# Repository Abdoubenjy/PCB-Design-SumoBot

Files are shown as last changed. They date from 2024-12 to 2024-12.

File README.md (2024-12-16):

# Sumo hardware
This repository contains the schematic and PCB design of a mini-class Sumobot (500g 10x10cm),
created in KiCad. It's a 2-layer PCB with microcontroller MSP430G2553IPW28,
regulators 3.3V (AMS1117-3.3) and 5V (MP2359), two motor drivers TB6612FNG, IR receiver TSP382, and
circuit protection (RS3E075AT).

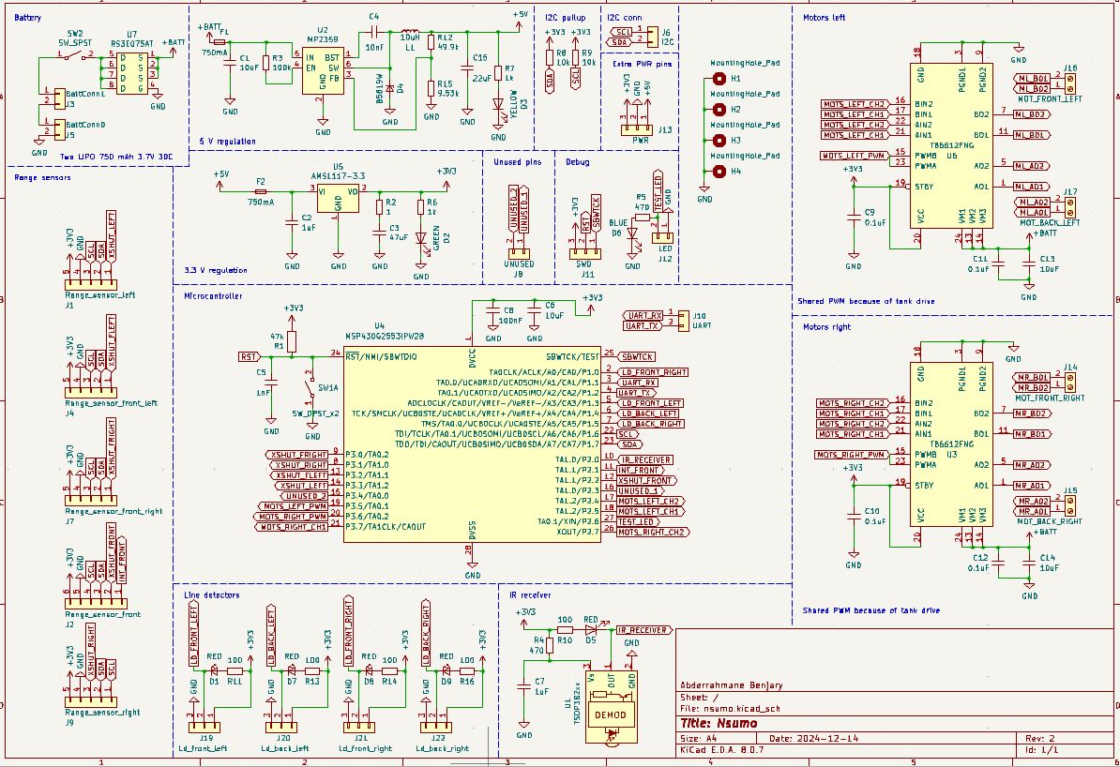
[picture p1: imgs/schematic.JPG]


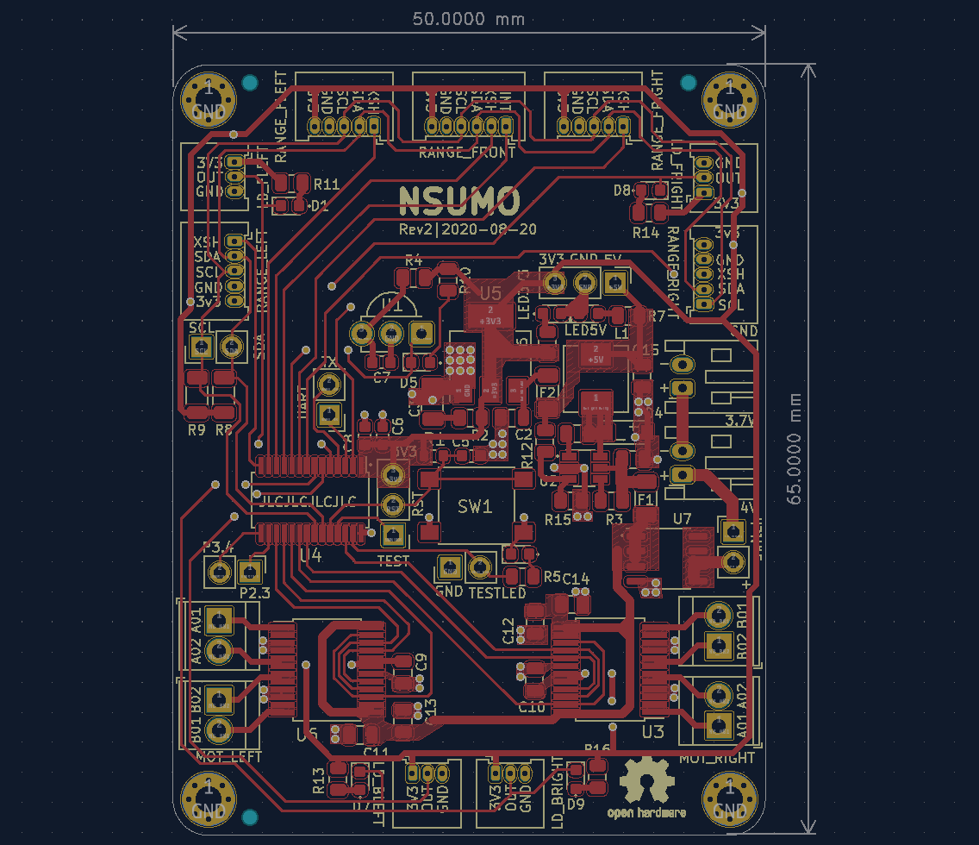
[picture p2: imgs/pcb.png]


## Setup
Import the project into KiCad >6.0 and make sure you have the "default global symbol library table"
and the "default footprint library" available. KiCad should find the 3Dmodels and symbols under _libs/_
automatically. You must manually import the footprints under _libs/footprints/_ (select "file/add library"
from the menu in the footprint editor and add them to the project).

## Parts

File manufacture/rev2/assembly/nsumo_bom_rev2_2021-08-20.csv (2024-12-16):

Comment | Designator | Footprint | LCSC Part #
10uF Unpolarized capacitor, small symbol | C13,C14,C1,C6 | C_0603_1608Metric | C19702
22uF Unpolarized capacitor, small symbol | C15 | C_0805_2012Metric | C45783
47uF Unpolarized capacitor, small symbol | C3 | C_1206_3216Metric | C96123
10nF Unpolarized capacitor, small symbol | C4 | C_0805_2012Metric | C1710
1nF Unpolarized capacitor, small symbol | C5 | C_0603_1608Metric | C1588
1uF Unpolarized capacitor, small symbol | C7,C2 | C_0805_2012Metric | C28323
100nF Unpolarized capacitor, small symbol | C8 | C_0603_1608Metric | C14663
0.1uF Unpolarized capacitor, small symbol | C9,C11,C12,C10 | C_0805_2012Metric | C49678
GREEN Light emitting diode | D2 | LED_0603_1608Metric | C72043
YELLOW Light emitting diode | D3 | LED_0603_1608Metric | C72038
B5819W Zener diode, small symbol | D4 | D_SOD-123 | C8598
RED Light emitting diode | D5 | LED_0603_1608Metric | C2286
BLUE Light emitting diode | D6 | LED_0603_1608Metric | C72041
RED Light emitting diode, small symbol | D7,D8,D9,D1 | LED_0603_1608Metric | C2286
750mA Fuse, small symbol | F2,F1 | Fuse_1206_3216Metric
MountingHole_Pad Mounting Hole with connection | H1,H2,H3,H4 | MountingHole_2.2mm_M2_Pad_Via
Range_sensor_left Generic connector, single row, 01x05, script generated (kicad-library-utils/schlib/autogen/connector/) | J1 | Molex_PicoBlade_53048-0510_1x05_P1.25mm_Horizontal
UART Generic connector, single row, 01x02, script generated (kicad-library-utils/schlib/autogen/connector/) | J10 | PinHeader_1x02_P2.54mm_Vertical
SWD Generic connector, single row, 01x03, script generated (kicad-library-utils/schlib/autogen/connector/) | J11 | PinHeader_1x03_P2.54mm_Vertical
LED Generic connector, single row, 01x02, script generated (kicad-library-utils/schlib/autogen/connector/) | J12 | PinHeader_1x02_P2.54mm_Vertical
PWR Generic connector, single row, 01x03, script generated (kicad-library-utils/schlib/autogen/connector/) | J13 | PinHeader_1x03_P2.54mm_Vertical
MOT_FRONT_RIGHT Generic screw terminal, single row, 01x02, script generated (kicad-library-utils/schlib/autogen/connector/) | J14 | TerminalBlock_TE_282834-2_1x02_P2.54mm_Horizont
MOT_BACK_RIGHT Generic screw terminal, single row, 01x02, script generated (kicad-library-utils/schlib/autogen/connector/) | J15 | TerminalBlock_TE_282834-2_1x02_P2.54mm_Horizont
MOT_FRONT_LEFT Generic screw terminal, single row, 01x02, script generated (kicad-library-utils/schlib/autogen/connector/) | J16 | TerminalBlock_TE_282834-2_1x02_P2.54mm_Horizont
MOT_BACK_LEFT Generic screw terminal, single row, 01x02, script generated (kicad-library-utils/schlib/autogen/connector/) | J17 | TerminalBlock_TE_282834-2_1x02_P2.54mm_Horizont
Ld_front_left Generic connector, single row, 01x03, script generated (kicad-library-utils/schlib/autogen/connector/) | J19 | Molex_PicoBlade_53048-0310_1x03_P1.25mm_Horizontal
Range_sensor_front Generic connector, single row, 01x06, script generated (kicad-library-utils/schlib/autogen/connector/) | J2 | Molex_PicoBlade_53048-0610_1x06_P1.25mm_Horizontal
Ld_back_left Generic connector, single row, 01x03, script generated (kicad-library-utils/schlib/autogen/connector/) | J20 | Molex_PicoBlade_53048-0310_1x03_P1.25mm_Horizontal
Ld_front_right Generic connector, single row, 01x03, script generated (kicad-library-utils/schlib/autogen/connector/) | J21 | Molex_PicoBlade_53048-0310_1x03_P1.25mm_Horizontal
Ld_back_right Generic connector, single row, 01x03, script generated (kicad-library-utils/schlib/autogen/connector/) | J22 | Molex_PicoBlade_53048-0310_1x03_P1.25mm_Horizontal
BattConn1 Generic connector, single row, 01x02, script generated (kicad-library-utils/schlib/autogen/connector/) | J3 | JST_PH_S2B-PH-K_1x02_P2.00mm_Horizontal
Range_sensor_front_left Generic connector, single row, 01x05, script generated (kicad-library-utils/schlib/autogen/connector/) | J4 | Molex_PicoBlade_53048-0510_1x05_P1.25mm_Horizontal
BattConn0 Generic connector, single row, 01x02, script generated (kicad-library-utils/schlib/autogen/connector/) | J5 | JST_PH_S2B-PH-K_1x02_P2.00mm_Horizontal
I2C Generic connector, single row, 01x02, script generated (kicad-library-utils/schlib/autogen/connector/) | J6 | PinHeader_1x02_P2.54mm_Vertical
Range_sensor_front_right Generic connector, single row, 01x05, script generated (kicad-library-utils/schlib/autogen/connector/) | J7 | Molex_PicoBlade_53048-0510_1x05_P1.25mm_Horizontal
UNUSED Generic connector, single row, 01x02, script generated (kicad-library-utils/schlib/autogen/connector/) | J8 | PinHeader_1x02_P2.54mm_Vertical
Range_sensor_right Generic connector, single row, 01x05, script generated (kicad-library-utils/schlib/autogen/connector/) | J9 | Molex_PicoBlade_53048-0510_1x05_P1.25mm_Horizontal
10uH Inductor, small symbol | L1 | L_Sunlord_MWSA0518_5.4x5.2mm | C408412
47k Resistor | R1 | R_0603_1608Metric | C25819
49.9k Resistor, small symbol | R12 | R_0805_2012Metric | C17719
100 Resistor, small symbol | R13,R14,R16,R11,R10 | R_0805_2012Metric | C17408
9.53k Resistor, small symbol | R15 | R_0805_2012Metric
1 Resistor, small symbol | R2 | R_0805_2012Metric | C25271
100k Resistor, small symbol | R3 | R_0805_2012Metric | C17407
470 Resistor, small symbol | R5,R4 | R_0805_2012Metric | C17710
1k Resistor, small symbol | R6,R7 | R_0805_2012Metric | C17513
10k Resistor, small symbol | R8,R9 | R_1206_3216Metric | C17902
SW_DPST_x2 Single Pole Single Throw (SPST) switch, separate symbol | SW1 | SW_Push_1P1T_NO_6x6mm_H9.5mm
SW_SPST Single Pole Single Throw (SPST) switch | SW2 | PinHeader_1x02_P2.54mm_Vertical
TSOP382xx Photo Modules for PCM Remote Control Systems | U1 | Vishay_MINICAST-3Pin
MP2359 | U2 | TSOT-23-6
MSP430G2553IPW28 1kB Flash, 256B RAM, TSSOP-28 | U4 | TSSOP-28_4.4x9.7mm_P0.65mm
AMS1117-3.3 1A Low Dropout regulator, positive, 1.5V fixed output, SOT-223 | U5 | SOT-223-3_TabPin2 | C6186
TB6612FNG Driver IC for Dual DC motor, SSOP-24 | U6,U3 | SSOP-24_5.3x8.2mm_P0.65mm_LongPads
RS3E075AT | U7 | SOP-8_3.9x4.9mm_P1.27mm

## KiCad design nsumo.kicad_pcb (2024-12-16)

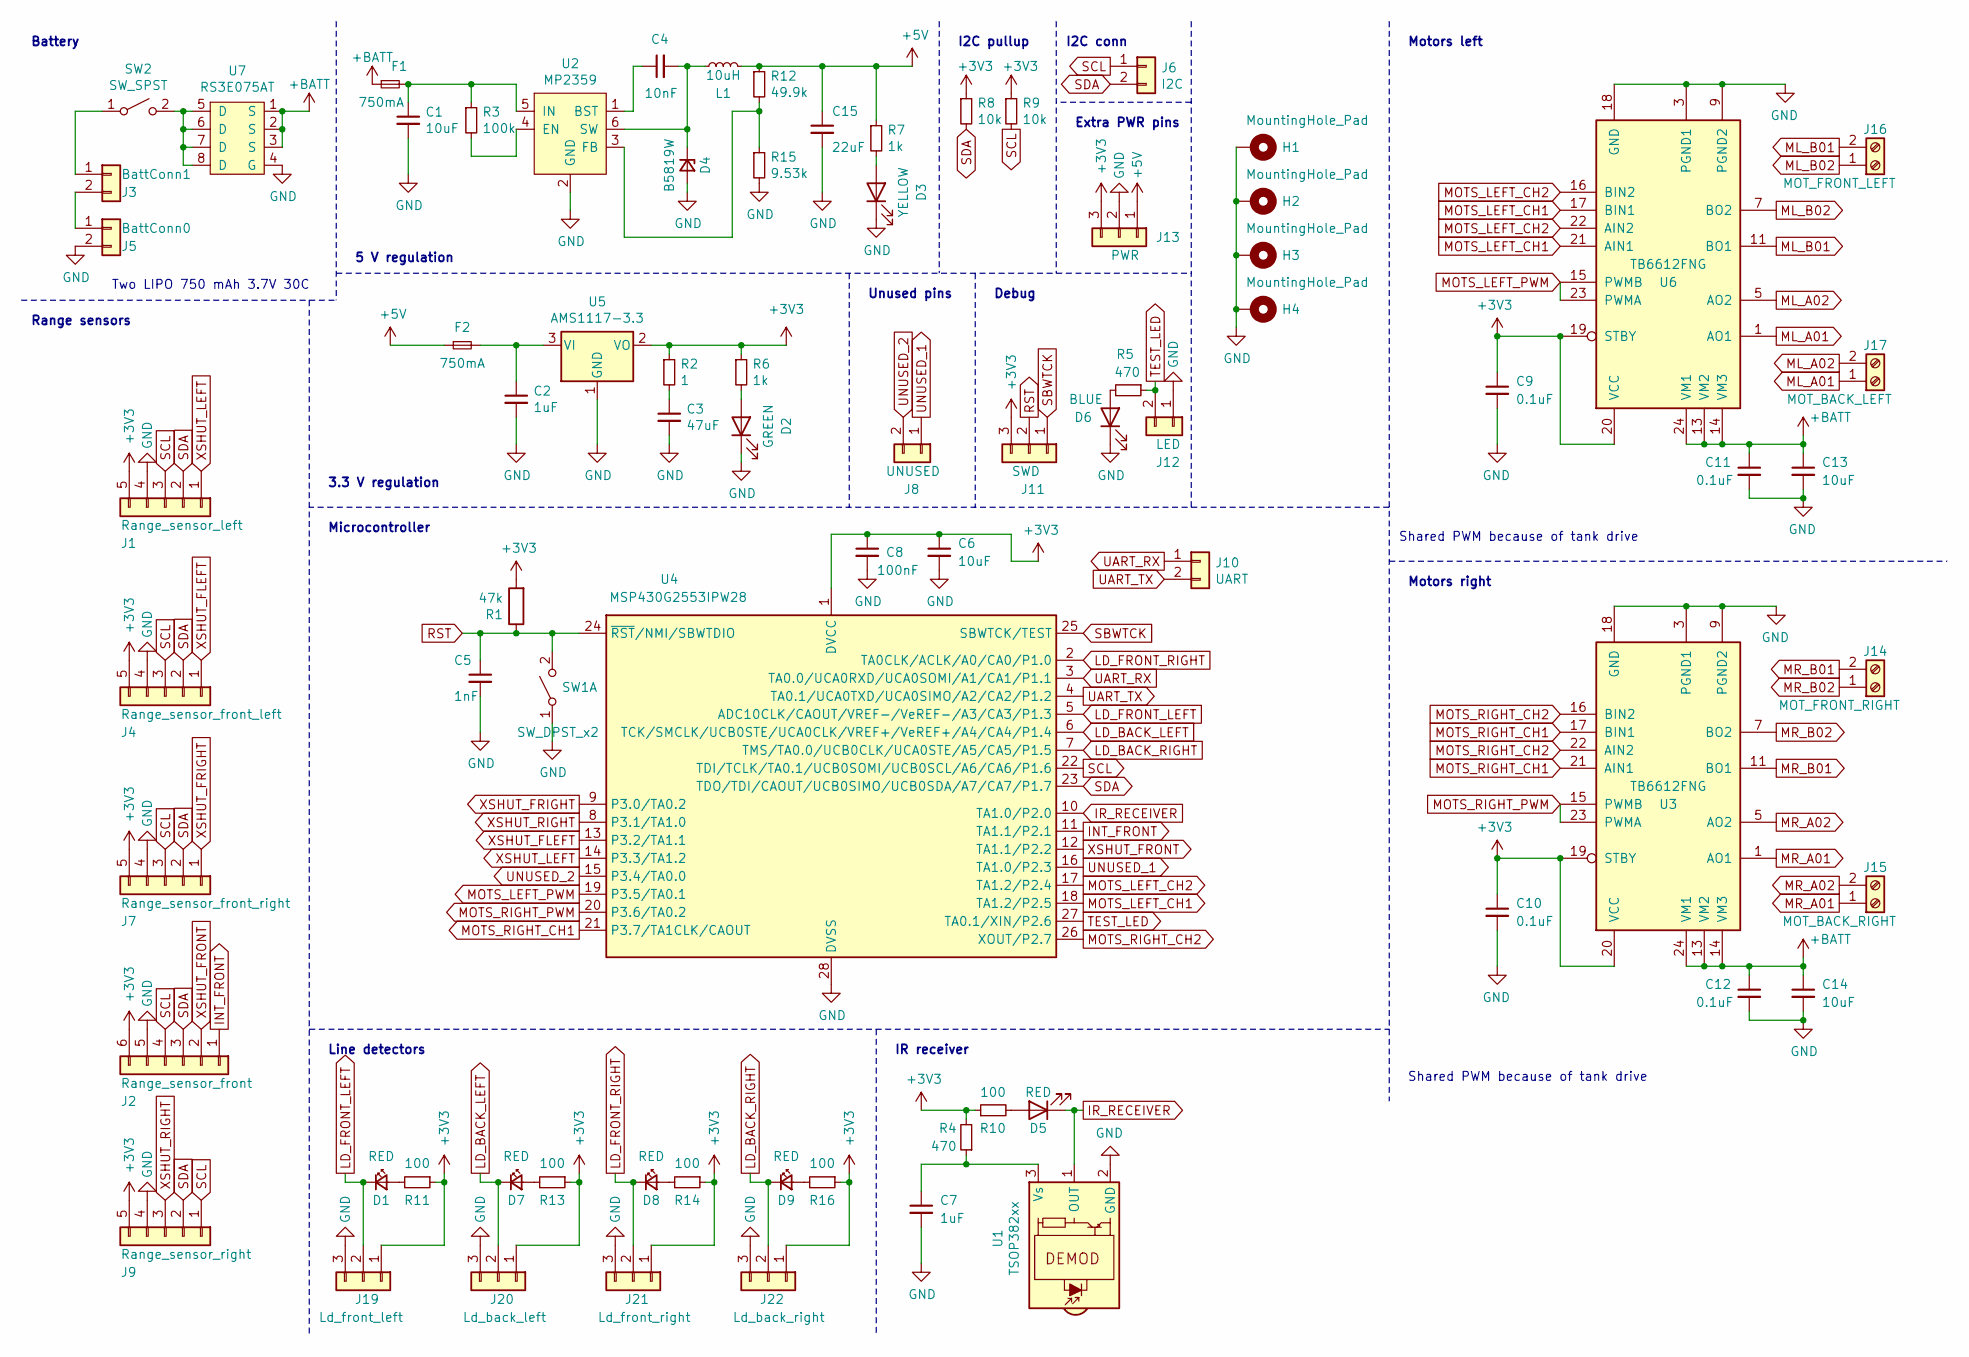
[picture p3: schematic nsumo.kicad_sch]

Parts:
C1, C13, C14: 10uF; C_0805_2012Metric; LCSC Part C15850
C2: 1uF; C_0805_2012Metric; LCSC Part C28323
C3: 47uF; C_1206_3216Metric; LCSC Part C96123
C4: 10nF; C_0805_2012Metric; LCSC Part C1710
C5: 1nF; C_0603_1608Metric; LCSC Part C1588
C6: 10uF; C_0603_1608Metric; LCSC Part C19702
C7: 1uF; C_0603_1608Metric; LCSC Part C15849
C8: 100nF; C_0603_1608Metric; LCSC Part C14663
C9, C10, C11, C12: 0.1uF; C_0805_2012Metric; LCSC Part C49678
C15: 22uF; C_0805_2012Metric; LCSC Part C45783
D1, D5, D7, D8, D9: RED; LED_0603_1608Metric; LCSC Part C2286
D2: GREEN; LED_0603_1608Metric; LCSC Part C72043
D3: YELLOW; LED_0603_1608Metric; LCSC Part C72038
D4: B5819W; D_SOD-123; LCSC Part C8598
D6: BLUE; LED_0603_1608Metric; LCSC Part C72041
F1, F2: 750mA; Fuse_1206_3216Metric
H1, H2, H3, H4: MountingHole_Pad; MountingHole_2.2mm_M2_Pad_Via
J1: Range_sensor_left; Molex_PicoBlade_53048-0510_1x05_P1.25mm_Horizontal
J2: Range_sensor_front; Molex_PicoBlade_53048-0610_1x06_P1.25mm_Horizontal
J3: BattConn1; JST_PH_S2B-PH-K_1x02_P2.00mm_Horizontal
J4: Range_sensor_front_left; Molex_PicoBlade_53048-0510_1x05_P1.25mm_Horizontal
J5: BattConn0; JST_PH_S2B-PH-K_1x02_P2.00mm_Horizontal
J6: I2C; PinHeader_1x02_P2.54mm_Vertical
J7: Range_sensor_front_right; Molex_PicoBlade_53048-0510_1x05_P1.25mm_Horizontal
J8: UNUSED; PinHeader_1x02_P2.54mm_Vertical
J9: Range_sensor_right; Molex_PicoBlade_53048-0510_1x05_P1.25mm_Horizontal
J10: UART; PinHeader_1x02_P2.54mm_Vertical
J11: SWD; PinHeader_1x03_P2.54mm_Vertical
J12: LED; PinHeader_1x02_P2.54mm_Vertical
J13: PWR; PinHeader_1x03_P2.54mm_Vertical
J14: MOT_FRONT_RIGHT; TerminalBlock_TE_282834-2_1x02_P2.54mm_Horizont
J15: MOT_BACK_RIGHT; TerminalBlock_TE_282834-2_1x02_P2.54mm_Horizont
J16: MOT_FRONT_LEFT; TerminalBlock_TE_282834-2_1x02_P2.54mm_Horizont
J17: MOT_BACK_LEFT; TerminalBlock_TE_282834-2_1x02_P2.54mm_Horizont
J19: Ld_front_left; Molex_PicoBlade_53048-0310_1x03_P1.25mm_Horizontal
J20: Ld_back_left; Molex_PicoBlade_53048-0310_1x03_P1.25mm_Horizontal
J21: Ld_front_right; Molex_PicoBlade_53048-0310_1x03_P1.25mm_Horizontal
J22: Ld_back_right; Molex_PicoBlade_53048-0310_1x03_P1.25mm_Horizontal
L1: 10uH; L_Sunlord_MWSA0518_5.4x5.2mm; LCSC Part C408412
R1: 47k; R_0603_1608Metric; LCSC Part C25819
R2: 1; R_0805_2012Metric; LCSC Part C25271
R3: 100k; R_0805_2012Metric; LCSC Part C17407
R4, R5: 470; R_0805_2012Metric; LCSC Part C17710
R6, R7: 1k; R_0805_2012Metric; LCSC Part C17513
R8, R9: 10k; R_1206_3216Metric; LCSC Part C17902
R10, R11, R13, R14, R16: 100; R_0805_2012Metric; LCSC Part C17408
R12: 49.9k; R_0805_2012Metric; LCSC Part C17719
R15: 9.53k; R_0805_2012Metric
SW1: SW_DPST_x2; SW_Push_1P1T_NO_6x6mm_H9.5mm
SW2: SW_SPST; PinHeader_1x02_P2.54mm_Vertical
U1: TSOP382xx; Vishay_MINICAST-3Pin
U2: MP2359; TSOT-23-6
U3, U6: TB6612FNG; SSOP-24_5.3x8.2mm_P0.65mm_LongPads
U4: MSP430G2553IPW28; TSSOP-28_4.4x9.7mm_P0.65mm
U5: AMS1117-3.3; SOT-223-3_TabPin2; LCSC Part C6186
U7: RS3E075AT; SOP-8_3.9x4.9mm_P1.27mm

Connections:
+3V3: C6.1, C8.1, C9.1, C10.1, J1.5, J2.6, J4.5, J7.5, J9.5, J11.3, J13.3, J19.1, J20.1, J21.1, J22.1, R1.2, R2.1, R4.2, R6.1, R8.1, R9.1, R10.1, R11.1, R13.1, R14.1, R16.1, U3.19 (STBY), U3.20 (VCC), U4.1 (DVCC), U5.2 (VO), U6.19 (STBY), U6.20 (VCC)
+5V: C15.1, F2.1, J13.1, L1.2, R7.1, R12.1
+BATT: C11.1, C12.1, C13.1, C14.1, F1.1, U3.13 (VM2), U3.14 (VM3), U3.24 (VM1), U6.13 (VM2), U6.14 (VM3), U6.24 (VM1), U7.1 (S), U7.2 (S), U7.3 (S)
GND: C1.2, C2.2, C3.2, C5.2, C6.2, C7.2, C8.2, C9.2, C10.2, C11.2, C12.2, C13.2, C14.2, C15.2, D2.1 (K), D3.1 (K), D4.2 (A), D6.1 (K), H1.1, H2.1, H3.1, H4.1, J1.4, J2.5, J4.4, J5.2, J7.4, J9.4, J12.1, J13.2, J19.3, J20.3, J21.3, J22.3, R15.2, SW1.1 (A), U1.2 (GND), U2.2 (GND), U3.3 (PGND1), U3.4 (PGND1), U3.9 (PGND2), U3.10 (PGND2), U3.18 (GND), U4.28 (DVSS), U5.1 (GND), U6.3 (PGND1), U6.4 (PGND1), U6.9 (PGND2), U6.10 (PGND2), U6.18 (GND), U7.4 (G)
INT_FRONT: J2.1, U4.11 (TA1.1/P2.1)
IR_RECEIVER: D5.1 (K), U1.1 (OUT), U4.10 (TA1.0/P2.0)
LD_BACK_LEFT: D7.1 (K), J20.2, U4.6 (TCK/SMCLK/UCB0STE/UCA0CLK/VREF+/VeREF+/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)
LD_BACK_RIGHT: D9.1 (K), J22.2, U4.7 (TMS/TA0.0/UCB0CLK/UCA0STE/A5/CA5/P1.5)
LD_FRONT_LEFT: D1.1 (K), J19.2, U4.5 (ADC10CLK/CAOUT/VREF-/VeREF-/A3/CA3/P1.3)
LD_FRONT_RIGHT: D8.1 (K), J21.2, U4.2 (TA0CLK/ACLK/A0/CA0/P1.0)
ML_A01: J17.1, U6.1 (AO1), U6.2 (AO1)
ML_A02: J17.2, U6.5 (AO2), U6.6 (AO2)
ML_B01: J16.2, U6.11 (BO1), U6.12 (BO1)
ML_B02: J16.1, U6.7 (BO2), U6.8 (BO2)
MOTS_LEFT_CH1: U4.18 (TA1.2/P2.5), U6.17 (BIN1), U6.21 (AIN1)
MOTS_LEFT_CH2: U4.17 (TA1.2/P2.4), U6.16 (BIN2), U6.22 (AIN2)
MOTS_LEFT_PWM: U4.19 (P3.5/TA0.1), U6.15 (PWMB), U6.23 (PWMA)
MOTS_RIGHT_CH1: U3.17 (BIN1), U3.21 (AIN1), U4.21 (P3.7/TA1CLK/CAOUT)
MOTS_RIGHT_CH2: U3.16 (BIN2), U3.22 (AIN2), U4.26 (XOUT/P2.7)
MOTS_RIGHT_PWM: U3.15 (PWMB), U3.23 (PWMA), U4.20 (P3.6/TA0.2)
MR_A01: J15.1, U3.1 (AO1), U3.2 (AO1)
MR_A02: J15.2, U3.5 (AO2), U3.6 (AO2)
MR_B01: J14.2, U3.11 (BO1), U3.12 (BO1)
MR_B02: J14.1, U3.7 (BO2), U3.8 (BO2)
unnamed: C1.1, F1.2, R3.1, U2.5 (IN)
unnamed: C2.1, F2.2, U5.3 (VI)
unnamed: C3.1, R2.2
unnamed: C4.1, U2.1 (BST)
unnamed: C4.2, D4.1 (K), L1.1, U2.6 (SW)
unnamed: C7.1, R4.1, U1.3 (Vs)
unnamed: D1.2 (A), R11.2
unnamed: D2.2 (A), R6.2
unnamed: D3.2 (A), R7.2
unnamed: D5.2 (A), R10.2
unnamed: D6.2 (A), R5.2
unnamed: D7.2 (A), R13.2
unnamed: D8.2 (A), R14.2
unnamed: D9.2 (A), R16.2
unnamed: J3.1, SW2.1 (A)
unnamed: J3.2, J5.1
unnamed: R3.2, U2.4 (EN)
unnamed: R12.2, R15.1, U2.3 (FB)
unnamed: SW2.2 (B), U7.5 (D), U7.6 (D), U7.7 (D), U7.8 (D)
RST: C5.1, J11.2, R1.1, SW1.2 (B), U4.24 (~RST/NMI/SBWTDIO)
SBWTCK: J11.1, U4.25 (SBWTCK/TEST)
SCL: J1.3, J2.4, J4.3, J6.1, J7.3, J9.1, R9.2, U4.22 (TDI/TCLK/TA0.1/UCB0SOMI/UCB0SCL/A6/CA6/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)
SDA: J1.2, J2.3, J4.2, J6.2, J7.2, J9.2, R8.2, U4.23 (TDO/TDI/CAOUT/UCB0SIMO/UCB0SDA/A7/CA7/P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)
TEST_LED: J12.2, R5.1, U4.27 (TA0.1/XIN/P2.6)
UART_RX: J10.1, U4.3 (TA0.0/UCA0RXD/UCA0SOMI/A1/CA1/P1.1)
UART_TX: J10.2, U4.4 (TA0.1/UCA0TXD/UCA0SIMO/A2/CA2/P1.2)
UNUSED_1: J8.1, U4.16 (TA1.0/P2.3)
UNUSED_2: J8.2, U4.15 (P3.4/TA0.0)
XSHUT_FLEFT: J4.1, U4.13 (P3.2/TA1.1)
XSHUT_FRIGHT: J7.1, U4.9 (P3.0/TA0.2)
XSHUT_FRONT: J2.2, U4.12 (TA1.1/P2.2)
XSHUT_LEFT: J1.1, U4.14 (P3.3/TA1.2)
XSHUT_RIGHT: J9.3, U4.8 (P3.1/TA1.0)

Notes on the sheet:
Battery
IR receiver
Shared PWM because of tank drive
Range sensors
3.3 V regulation
Two LIPO 750 mAh 3.7V 30C
Line detectors
Microcontroller
Extra PWR pins
I2C conn
5 V regulation
I2C pullup
Motors right
Motors left
Unused pins
Debug

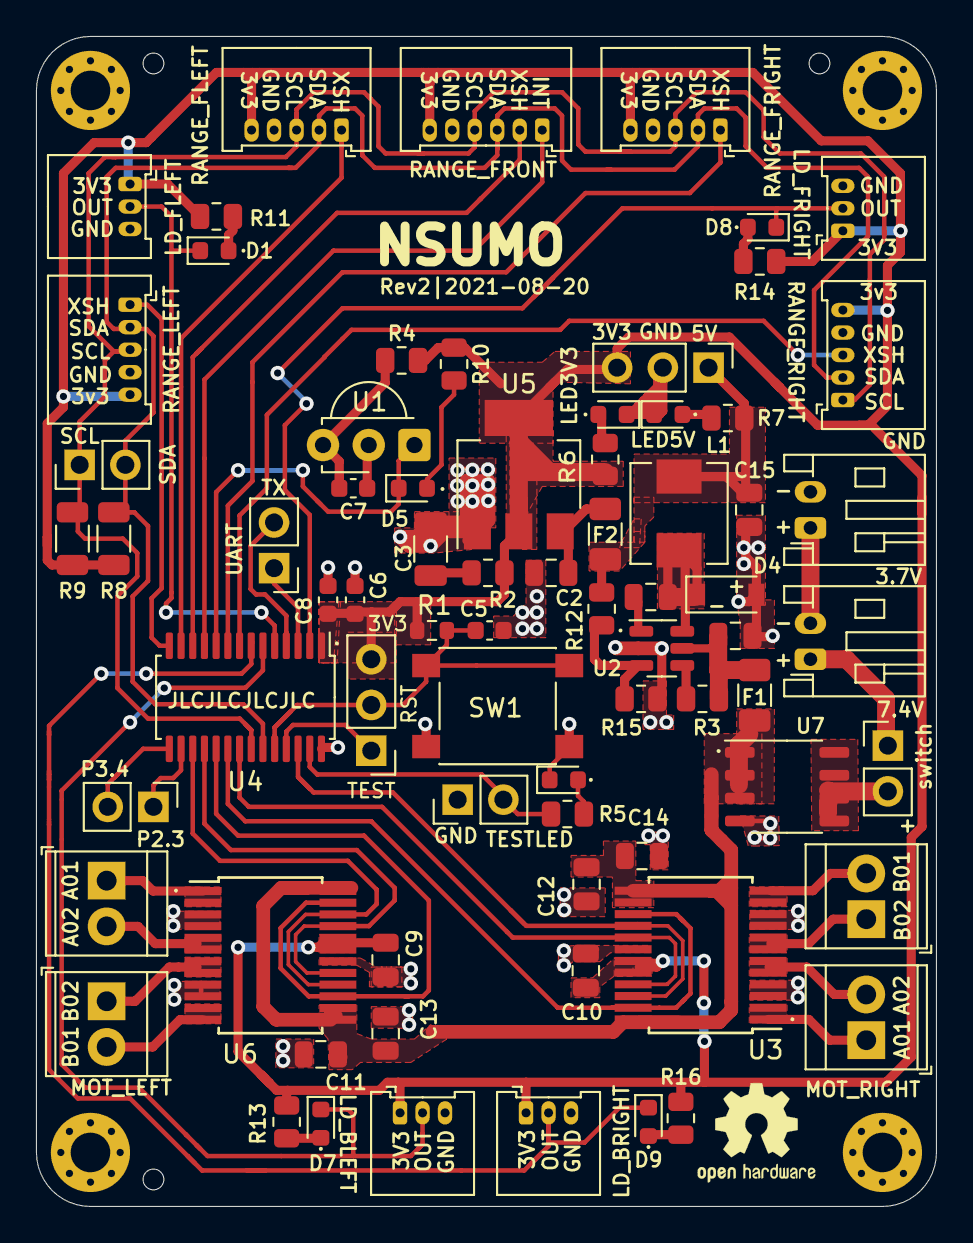
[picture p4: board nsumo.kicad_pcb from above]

Board: 2 copper layers, 50.0 x 65.0 mm, 77 parts (0 on the bottom side), 57 nets.
